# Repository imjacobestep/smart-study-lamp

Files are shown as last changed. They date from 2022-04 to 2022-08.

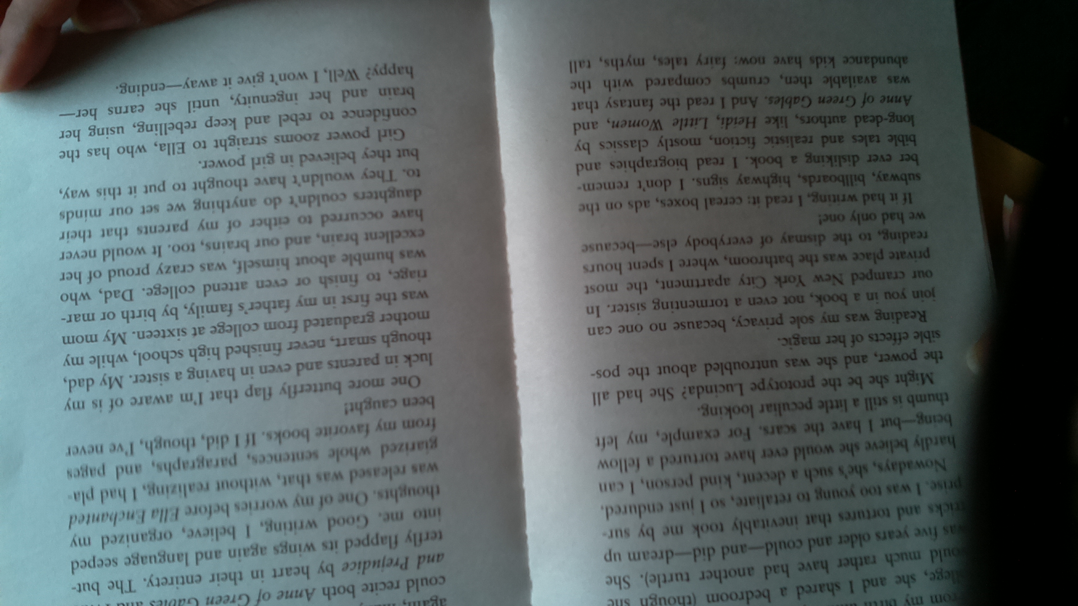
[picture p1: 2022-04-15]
test_code/past_camera_test/photos/photos with raspberry pi cam/test3.jpg

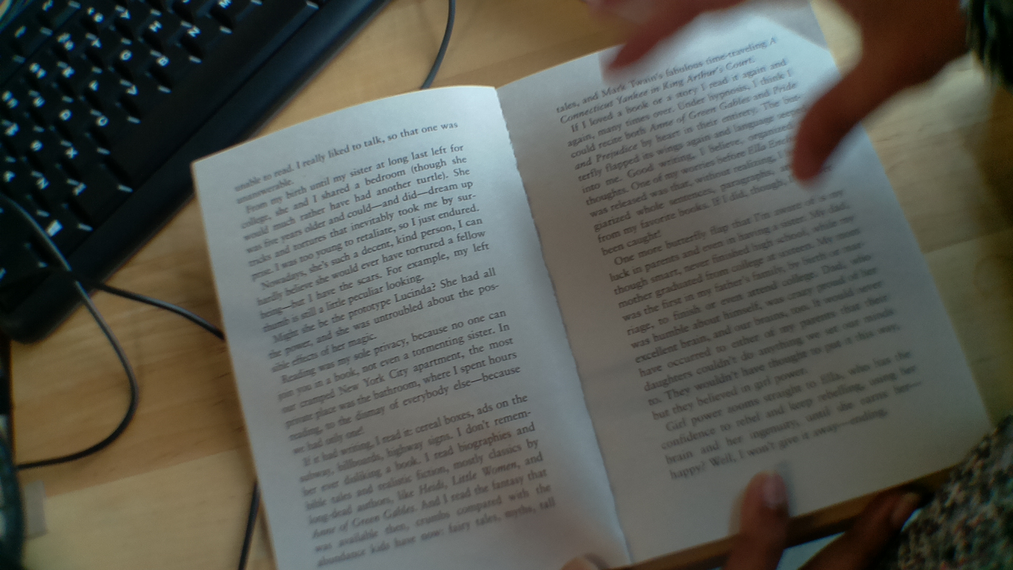
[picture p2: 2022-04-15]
test_code/past_camera_test/photos/photos with lens 2/test2.jpg

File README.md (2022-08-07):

This contains the main code for a smart study lamp prototype made as a project for GIX TECHIN 515 Hardware/Software Lab 2 in Spring 2022

# Variables:
These values are centralized in utilities.py: <br />
pin numbers <br />
color values <br />
crop dimensions (box above finger, for text extraction) <br />
target brightness <br />
finger jitter correction tolerance <br />
word distance-from-finger margin <br />

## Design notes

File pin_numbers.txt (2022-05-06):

Pin layouts
LED data pin: GPIO 10
LED switch pin: GPIO 5
Brightness button pin: GPIO 17
Color button pin: GPIO 27
Camera switch pin: GPIO 19

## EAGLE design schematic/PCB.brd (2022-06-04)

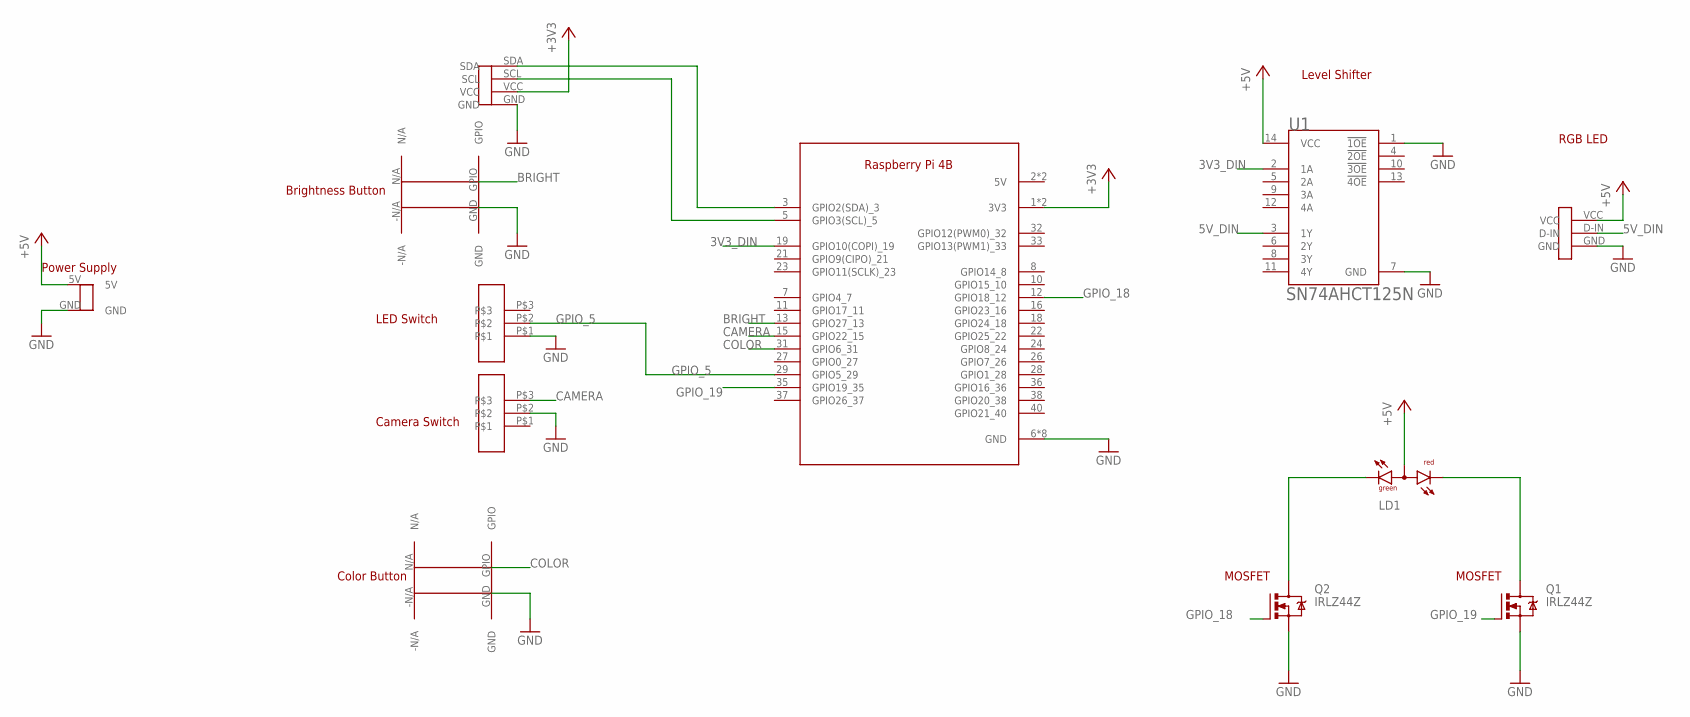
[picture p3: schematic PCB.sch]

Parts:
LD1: DUOLED-RG-A; DUOLED-A-5MM
Q1, Q2: IRLZ44Z; TO220BH
U1: TEXAS_INSTRUMENTS_SN74AHCT125NTEXAS_INSTRUMENTS_S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; TEXAS_INSTRUMENTS_SN74AHCT125N_0
U$1: RASPBERRY_PI_4; RASPI_4B
U$2, U$3: G13-SW
U$4: LIGHTSENSOR-PO; LIGHTSENSOR-IO
U$5: LED-STRIP-PO
U$6, U$7: G13-BUTTON
U$8: G13-BATTERY

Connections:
3V3_DIN: U1.2 (1A), U$1.19 (GPIO10(COPI)_19)
5V_DIN: U1.3 (1Y), U$5.D-IN
+3V3: U$1.1 (3V3), U$1.17 (3V3), U$4.VCC
+5V: LD1.A, U1.14 (VCC), U$5.VCC, U$8.5V
BRIGHT: U$1.13 (GPIO27_13), U$6.GPIO
CAMERA: U$1.15 (GPIO22_15), U$3.P$3
COLOR: U$1.31 (GPIO6_31), U$7.GPIO
GND: Q1.S, Q2.S, U1.1 (!1OE!), U1.7 (GND), U$1.6 (GND), U$1.9 (GND), U$1.14 (GND), U$1.20 (GND), U$1.25 (GND), U$1.30 (GND), U$1.34 (GND), U$1.39 (GND), U$2.P$1, U$3.P$2, U$4.GND, U$5.GND, U$6.GND, U$7.GND, U$8.GND
GPIO_5: U$1.29 (GPIO5_29), U$2.P$2
GPIO_18: Q2.G, U$1.12 (GPIO18_12)
GPIO_19: Q1.G, U$1.35 (GPIO19_35)
unnamed: U$1.3 (GPIO2(SDA)_3), U$4.SDA
unnamed: U$1.5 (GPIO3(SCL)_5), U$4.SCL
unnamed: LD1.CR, Q1.D
unnamed: LD1.CX (CG), Q2.D

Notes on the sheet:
Brightness Button
Color Button
Level Shifter
Power Supply
MOSFET
RGB LED
LED Switch
Camera Switch

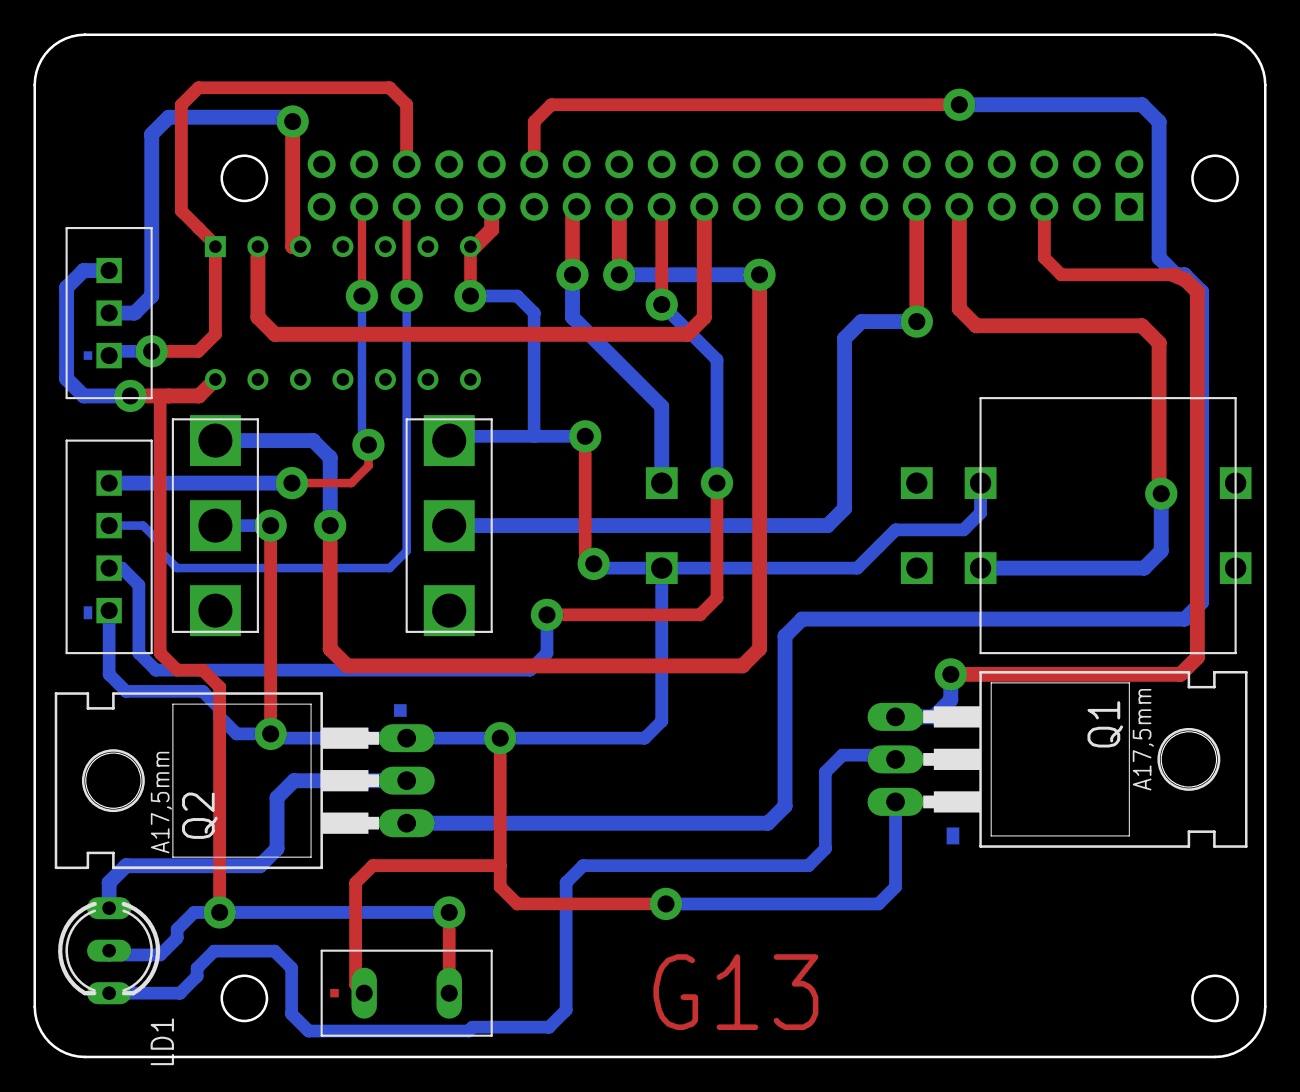
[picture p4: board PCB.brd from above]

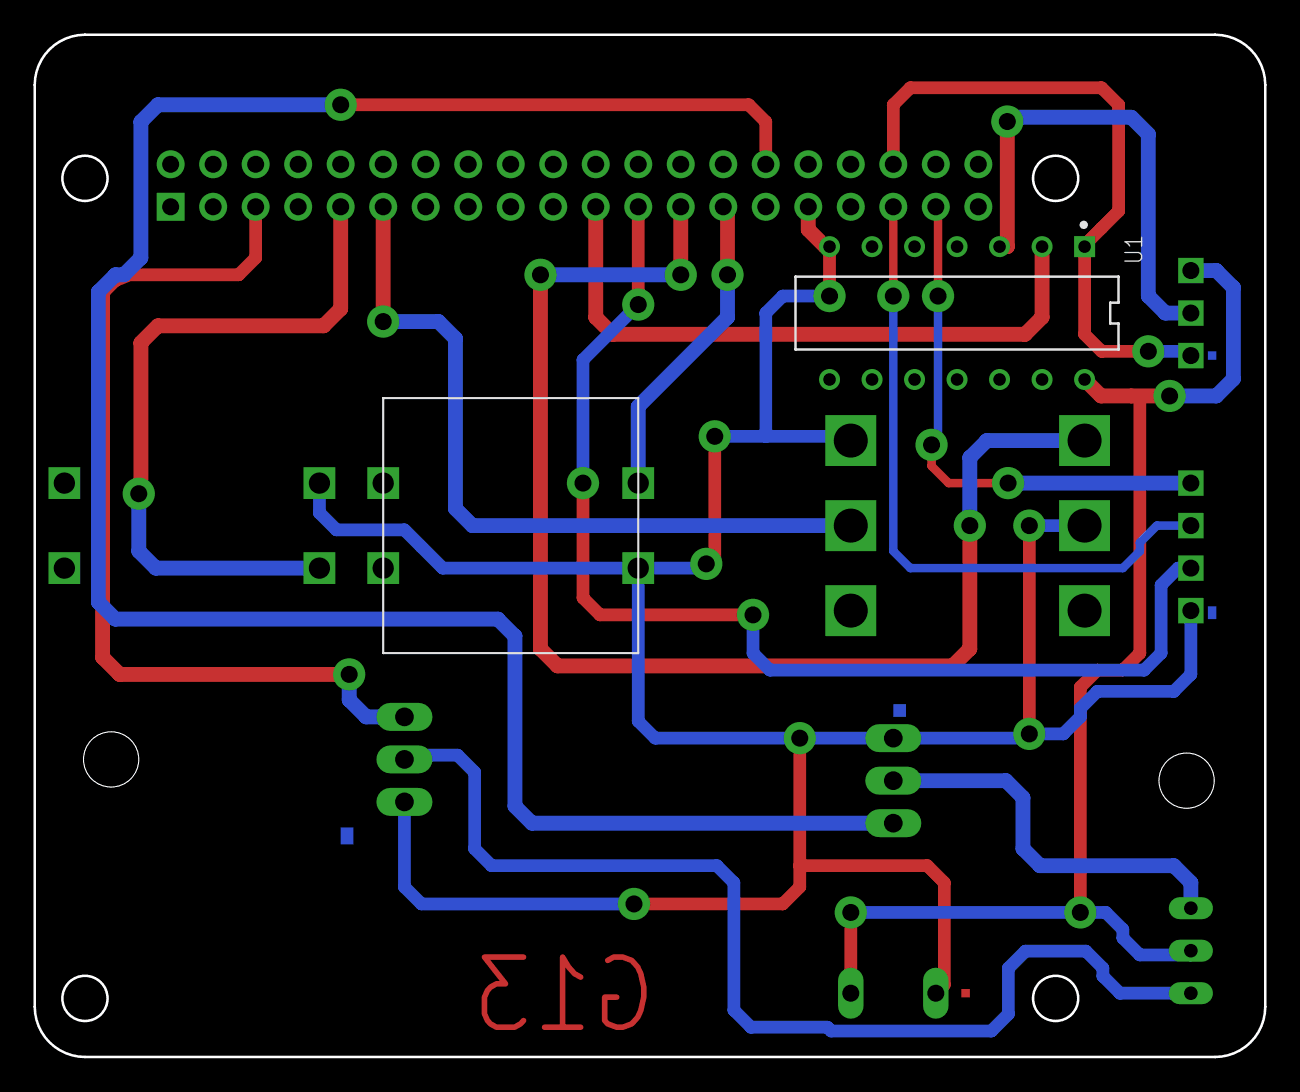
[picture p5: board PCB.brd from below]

Board: 2 copper layers, 73.5 x 61.1 mm, 12 parts (2 on the bottom side), 15 nets.

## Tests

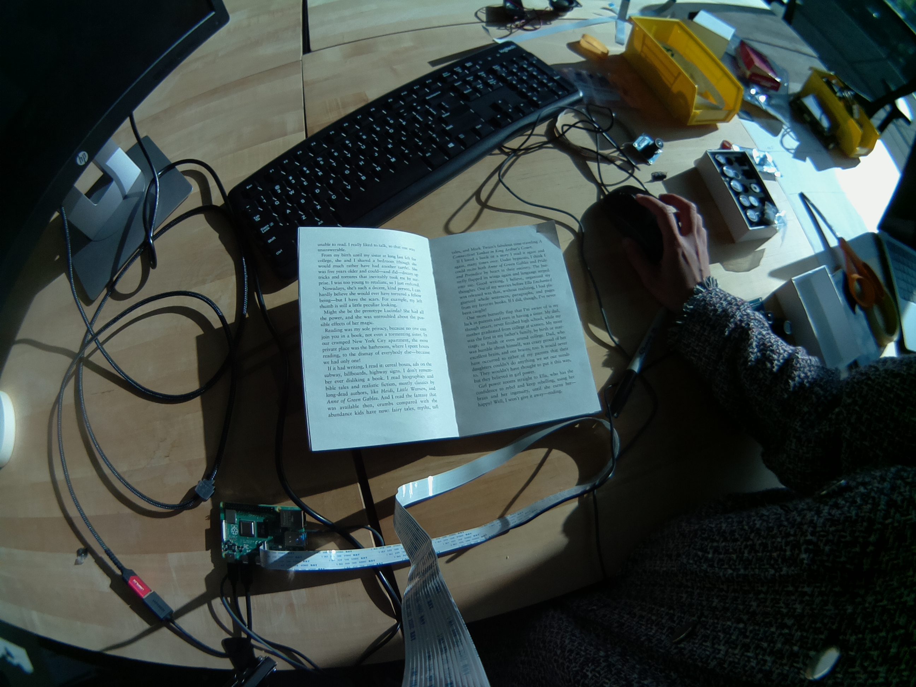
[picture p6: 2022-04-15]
test_code/past_camera_test/photos/photos with lens 1/img2_stand.jpg

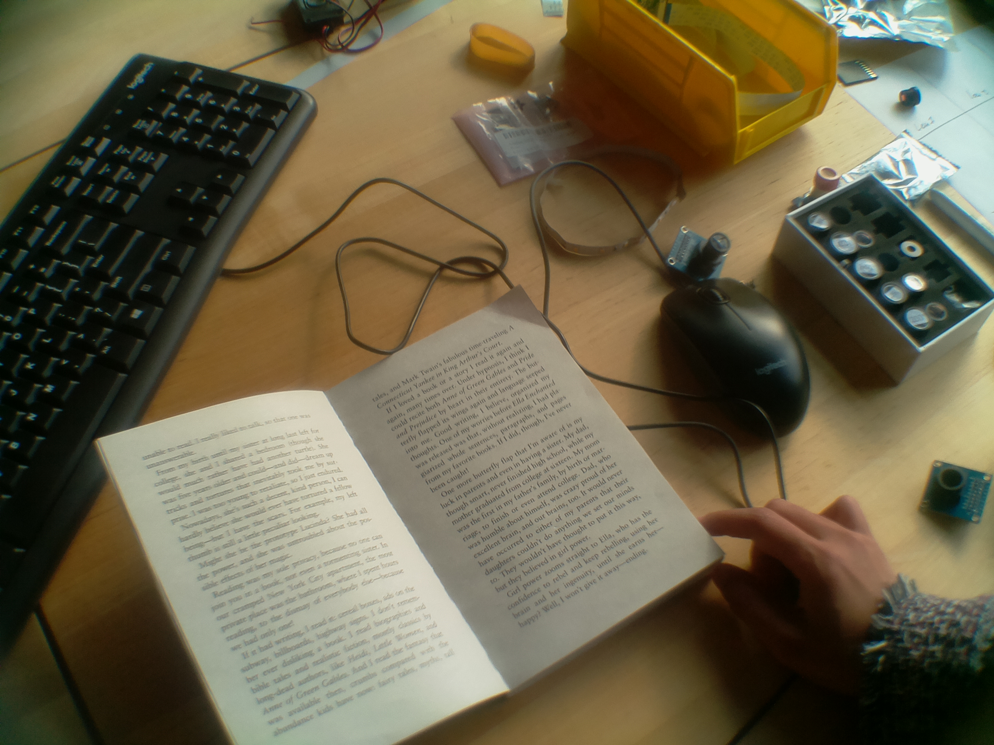
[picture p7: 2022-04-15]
test_code/past_camera_test/photos/photos with lens 2/img2_stand.jpg

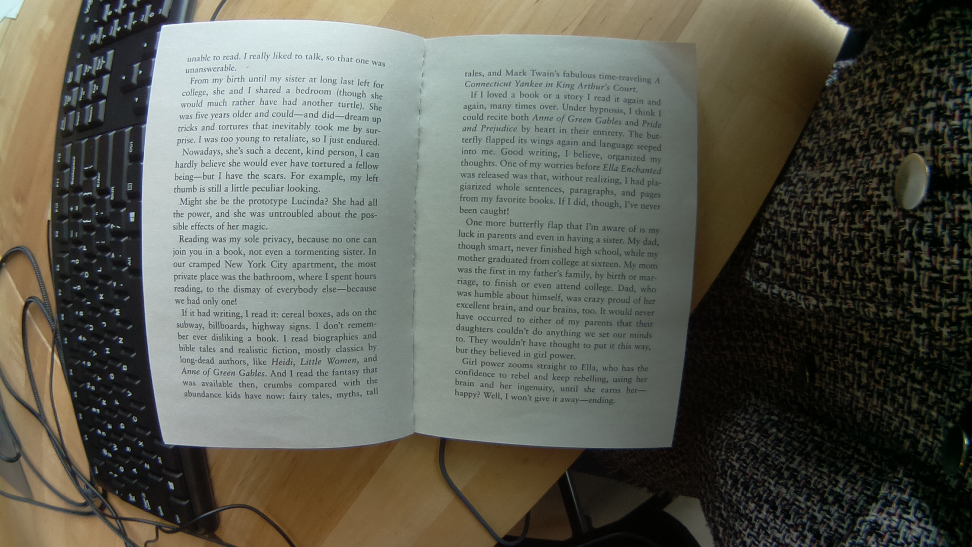
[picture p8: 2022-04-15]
test_code/past_camera_test/photos/photos with lens 1/test1.jpg

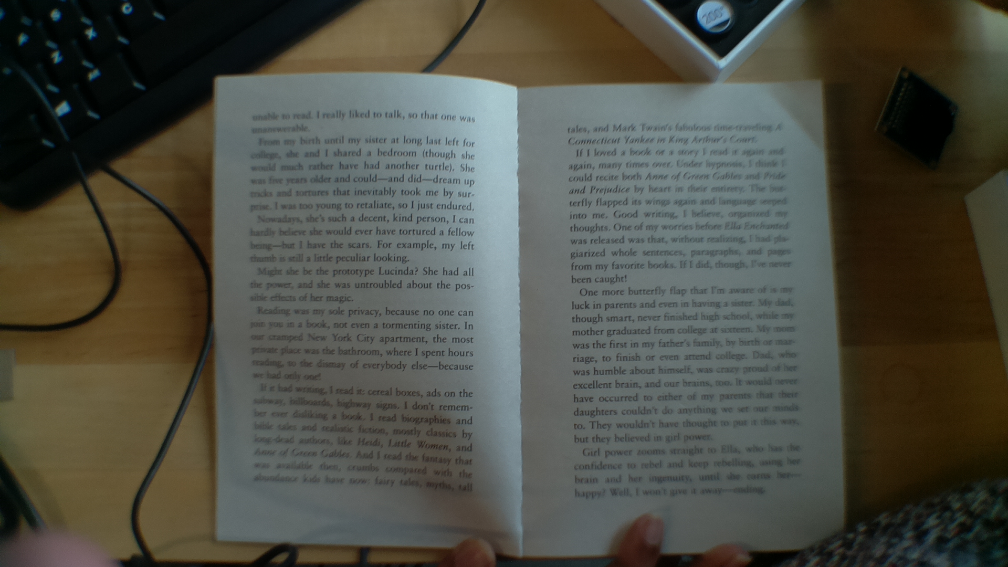
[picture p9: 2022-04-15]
test_code/past_camera_test/photos/photos with lens 2/test1.jpg

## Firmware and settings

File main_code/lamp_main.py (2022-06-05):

## IMPORTS ##
from tracemalloc import stop
import environment_service
import camera_service
import utilities
import threading
import RPi.GPIO as GPIO
import mediapipe as mp
from picamera import PiCamera
from picamera.array import PiRGBArray
from io import BytesIO
import time
import cv2
from gpiozero import Button

## VARIABLES ##
lock = threading.Lock()

camera_switch = True
btnBrightness=Button(utilities.pin_table["led brightness"])
btnColor=Button(utilities.pin_table["led color"])
mp_drawing = mp.solutions.drawing_utils
mp_drawing_styles = mp.solutions.drawing_styles
mp_hands = mp.solutions.hands
camera = PiCamera()
rawCapture = PiRGBArray(camera)
camera.resolution = (1920, 1080)
camera.framerate = 30
rawCapture = PiRGBArray(camera, size=(1920, 1080))
time.sleep(0.1)
#camera.use_video_port = True
stream = BytesIO()

GPIO.setmode(GPIO.BCM)
GPIO.setup(utilities.pin_table["auto switch"], GPIO.IN, pull_up_down=GPIO.PUD_UP) #auto switch
GPIO.setup(utilities.pin_table["led brightness"], GPIO.IN, pull_up_down=GPIO.PUD_UP) #LED brightness button
GPIO.setup(utilities.pin_table["led color"], GPIO.IN, pull_up_down=GPIO.PUD_UP) #LED color button
GPIO.setup(utilities.pin_table["camera switch"], GPIO.IN, pull_up_down=GPIO.PUD_UP) #camera switch

## FUNCTIONS ##
def check_pin(pin):
    if GPIO.input(utilities.pin_table[pin]):
        return True
    return False

def camera_change():
    global camera_switch
    if check_pin("camera switch"):
        if not camera_switch:
            start_camera()
            return
    else:
        if camera_switch:
            stop_camera()
            return
    print("no camera change")

def start_camera():
    global lock, camera_switch
    #lock.acquire()
    camera_switch = True
    print("camera on")
    #lock.release()
    if not camera_thread.is_alive():
        camera_thread.start()

def stop_camera():
    global lock, camera_switch
    #lock.acquire()
    camera_switch = False
    print("camera off")
    #lock.release()
    if camera_thread.is_alive():
        camera_thread.join()

def camera_loop(lock):
    global camera_switch
    print("camera started")
    cap = cv2.VideoCapture(-1)
    x,y = 0,0
    with mp_hands.Hands(
        min_detection_confidence=0.5,
        min_tracking_confidence=0.5) as hands:
            for frame in camera.capture_continuous(rawCapture, format="bgr", use_video_port=True):
                image = frame.array
                image = cv2.cvtColor(image, cv2.COLOR_BGR2RGB)
                results = hands.process(image)
                image.flags.writeable = True
                image = cv2.cvtColor(image, cv2.COLOR_RGB2BGR)
                image_height, image_width, _ = image.shape
                if results.multi_hand_landmarks:
                    for hand_landmarks in results.multi_hand_landmarks:
                        x = hand_landmarks.landmark[mp_hands.HandLandmark.INDEX_FINGER_TIP].x * image_width
                        y = hand_landmarks.landmark[mp_hands.HandLandmark.INDEX_FINGER_TIP].y * image_height
                        print("Index fingertip at: " + str(x) + ", " + str(y))
                        camera_service.track_movement(image, x,y)
                        mp_drawing.draw_landmarks(
                            image,
                            hand_landmarks,
                            mp_hands.HAND_CONNECTIONS,
                            mp_drawing_styles.get_default_hand_landmarks_style(),
                            mp_drawing_styles.get_default_hand_connections_style())
                cv2.imshow('MediaPipe Hands', cv2.resize(camera_service.draw_rectangle(image=image, x=x, y=y), (852,480)))
                rawCapture.truncate(0)
                lock.acquire()
                cont = camera_switch
                lock.release()
                if not cont:
                    break
    cap.release()
    print("camera ended")

## MAIN LOOP ##
camera_switch = GPIO.input(utilities.pin_table["camera switch"])
camera_thread = threading.Thread(target=camera_loop, args=(lock, ))
counter=0

#environment_service.rgb_update(brightness=0, color=[0,0,0])


while True:
    #csamera management
    #Commented by Sumayyah
    #if GPIO.input(utilities.pin_table["auto switch"]) and not camera_switch:
        #camera_switch = True
     #   start_camera()
    #elif (not GPIO.input(utilities.pin_table["auto switch"])) and camera_switch:
        #camera_switch = False
     #   stop_camera()
    #End Commented by Sumayyah

    #led management
    IsAuto=GPIO.input(utilities.pin_table["auto switch"])
    if IsAuto:
        environment_service.auto_adjust()
        print("led auto adjust")
    else:
        print("led manual adjust")
        if btnColor.is_pressed:
            environment_service.manual_color()
            print(f"manual color change {counter}")
            #time.sleep(0.2)
        if btnBrightness.is_pressed:
            environment_service.manual_brightness()
            print("manual brightness change")
    time.sleep(0.2)
    counter+=1
    

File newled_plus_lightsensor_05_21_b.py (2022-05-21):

import time
import board
import adafruit_tsl2591
import neopixel
from datetime import datetime
import RPi.GPIO as GPIO
from gpiozero import Button
import pigpio
import numpy as np

from rpi_hardware_pwm import HardwarePWM as hpwm


# PINcool=18
# PINwarm=19
PINMode=5
PINBrightness= 27
PINColor= 6


GPIO.setmode(GPIO.BCM)

GPIO.setup(PINMode, GPIO.IN, pull_up_down=GPIO.PUD_UP)
GPIO.setup(PINBrightness, GPIO.IN, pull_up_down=GPIO.PUD_UP)
GPIO.setup(PINColor, GPIO.IN, pull_up_down=GPIO.PUD_UP)



btnBrightness=Button(PINBrightness)
btnColor=Button(PINColor)

pwm_cool=hpwm(pwm_channel=0,hz=20000)
pwm_warm=hpwm(pwm_channel=1,hz=20000)

pwm_cool.start(0)
pwm_warm.start(0)

green=[0,255,40]
pixel_pin = board.D10
num_pixels = 60

ORDER = neopixel.GRB

pixels = neopixel.NeoPixel(
    pixel_pin, num_pixels, brightness=1, auto_write=False, pixel_order=ORDER
)
pixels.fill(green)
pixels.show()

i2c = board.I2C()  
sensor = adafruit_tsl2591.TSL2591(i2c)
sensor.gain = adafruit_tsl2591.GAIN_HIGH


def set_color(colind):
    global oldcolind,oldbrightness,brightness

    if colind!=oldcolind or brightness!=oldbrightness:
        print(colind,brightness)
        if colind==0:
            pwm_cool.change_duty_cycle(brightness)
            pwm_warm.change_duty_cycle(0)
        elif colind==2:
            pwm_cool.change_duty_cycle(0)
            pwm_warm.change_duty_cycle(brightness)
        else:
            pwm_cool.change_duty_cycle(brightness/2)
            pwm_warm.change_duty_cycle(brightness/2)
        oldcolind=colind
        oldbrightness=brightness

currenttime=datetime.now().strftime("%H:%M:%S")
if "06:00:00" < currenttime < "17:00:00":
    colorindex=0
else:
    colorindex=2
    
IsManual=False





oldcolind=-1
oldbrightness=0
brightness=50
target_luxvalue=70
set_color(colorindex)


while True:

    IsManual = GPIO.input(PINMode)
    luxvalue = sensor.visible/1e6 #sensor.lux
    print(luxvalue)

    if IsManual:
        print("manual")
        
        if btnBrightness.is_pressed:
            brightness+=20
            if brightness>100:
                brightness=0
            set_color(colorindex)
            
        if btnColor.is_pressed:
            colorindex+=1
            if colorindex>2:
                colorindex=0
            set_color(colorindex)
            
    else:
        print("auto")
        
        currenttime = datetime.now().strftime("%H:%M:%S")
        if "06:00:00" < currenttime < "17:00:00":
            if colorindex!=0:
                colorindex=0
                set_color(colorindex)
        else:
            if colorindex!=2:
                colorindex=2
                set_color(colorindex)

        #print(colorindex)
        luxvalue = sensor.visible/1e6 #sensor.lux
        error=target_luxvalue-luxvalue
        print(f"lux={luxvalue},   brightness={brightness}, error={error}")
        if error!=0:
            brightness=brightness+0.1*error
            if brightness>100: brightness=100
            if brightness<0: brightness=0
            set_color(colorindex)
            print(f"***lux={luxvalue},   brightness={brightness}, error={error}")
   
    time.sleep(0.2)
    

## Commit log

2022-04-17 Added camera button code into lamp.py
2022-04-22 Added gesture tracking
    I got the gesture tracking test code working. A swipe gesture will trigger a "page turn" and a point (after lingering for a few seconds) will trigger the word lookup feature for the word the fingerti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
2022-04-29 Worked on consolidating code. Camera service is mostly done, initial multithreading
2022-05-04 Added pin number table image
2022-05-06 New Pin numbers file
    Swapped the pin number image with an editable text file, now with updates values
    [environment_service.py]
2022-05-06 Updated all pin references to point back to pin table
2022-05-06 added camera test with live view
2022-05-06 some minor bug fixes, modified light service
    [camera_service.py, environment_service.py]
2022-05-07 finger coords print error fixed
    [camera_service.py, main_test.py]
2022-05-09 camera switch bugfix
2022-05-09 camera change bugfix
2022-05-09 updated packages script, bugfixes
    [camera_service.py]
2022-05-09 re-wrote ocr test to work on pi, hopefully to diagnose issues in m2
    [ocr_test.py]
2022-05-13 added 3rd camera test method using still images
2022-05-20 finished new LED integration, streamlined everything else
2022-05-20 fixed env test error
    [camera_service.py, main_test.py]
2022-05-20 fixed camera test issue
    [camera_service.py, main_test.py]
2022-05-23 added new LED changes to reduce flicker into main code
2022-05-26 added code to correct rgb color change over 255
    [environment_service.py]
2022-05-27 added print statements to camera toggle
2022-05-28 pin numbers update
2022-05-29 testing main loop fixes
    [lamp_main.py]
2022-05-29 added print statements to main loop for clarity
2022-05-30 Sumayyah: Checked that leds work (firebase disabled)
2022-06-01 added camera running print statements
2022-06-02 Fixed rgb LED issues when word selected
    [camera_service.py, environment_service.py]
2022-06-05 modify led manual mode
